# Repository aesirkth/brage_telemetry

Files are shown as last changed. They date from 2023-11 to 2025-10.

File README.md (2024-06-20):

## Brage Telemetry modem
Brage is a 1W 2.4GHz Telemetry modem that can listen and transmit from a CAN-bus. The name comes from the norse god of poetry, Brage, who will tell the tales of the rocket.

| front | back |
|---|---|
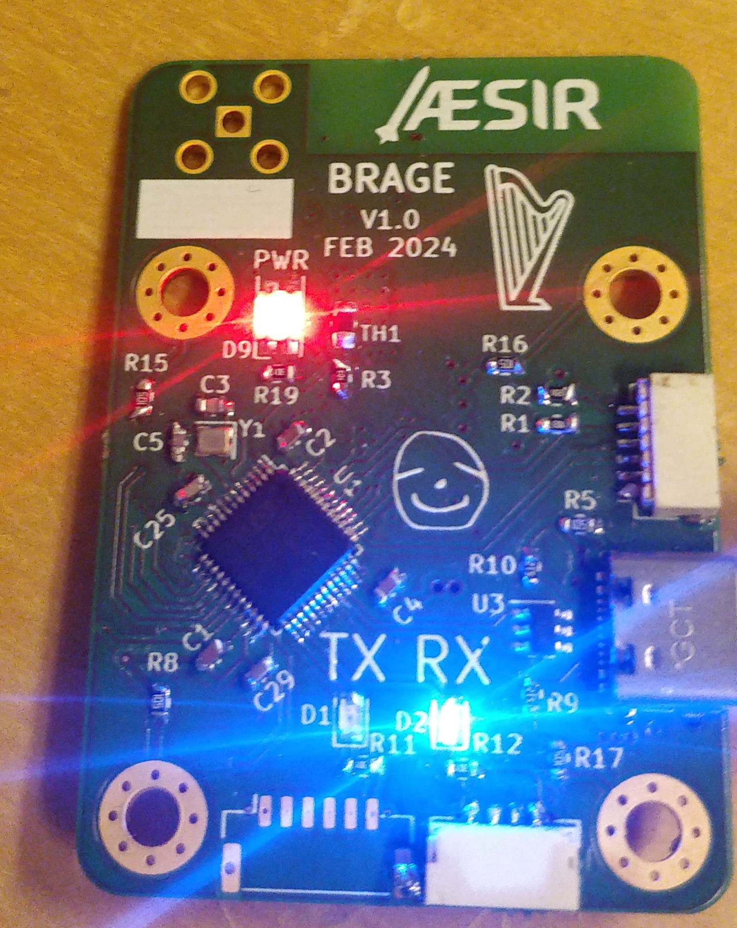
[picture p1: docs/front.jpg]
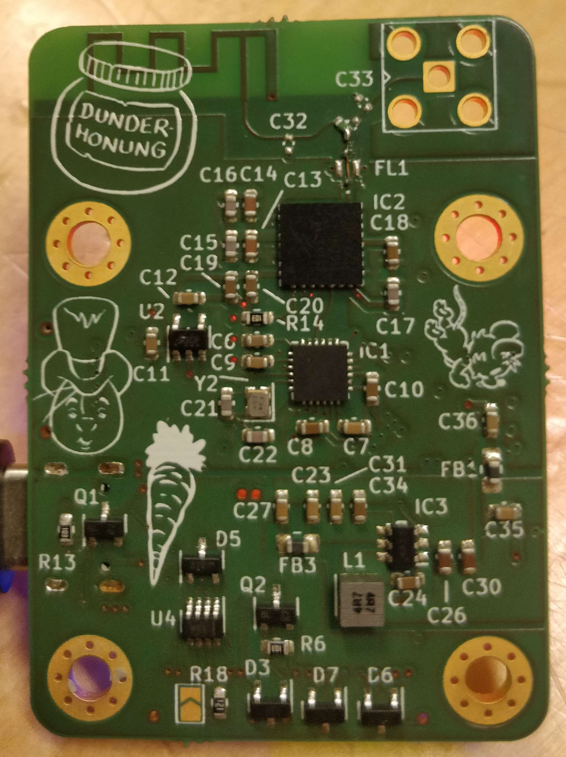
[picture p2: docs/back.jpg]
| | |

### Features
* 2Mbit/s
* Time of Flight ranging
* CAN FD with SIC
* UART
* USB
* PCB antenna

### Hardware
The modem is based on an STM32U575CG and an SX1280 transceiver. The radio signal is put through a frontend, filtering and amplifying it to 30dBm. The UART and CAN connectors follow the PixHawk standard while the debugging port is custom.

### Firmware
The firmware is being developed using Rust with Embassy.
See the firmware [README](firmware/README.md)

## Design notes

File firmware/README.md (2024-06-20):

## Brage firmware
### Building
Brage is built using Rust and the Embassy framework. `cargo build --release`. I don't have a proper build guide yet but cargo should point out the missing dependencies (I think). Cargo should fetch most of the dependencies itself. You might need to install at least rustup and Probe-rs yourself.

To flash the board, just run `cargo run --release`

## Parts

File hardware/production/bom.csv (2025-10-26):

Designator | Footprint | Quantity | Value | LCSC Part #
AE1 | Texas_SWRA117D_2.4GHz_Left | 1 | inverted F
C1, C13, C14, C2, C4 | 0603 | 5 | 4u7
C10, C18, C19, C20, C24, C25, C29, C34, C8 | 0603 | 9 | 100n
C11, C12, C23, C27, C31, C35, C36, C7 | 0603 | 8 | 1u
C15, C16, C17, C21, C22, C3, C5 | 0603 | 7 | 18p
C26, C30 | 0603 | 2 | 10u
C32, C33 | 0402 | 2 | TBD
C6, C9 | 0603 | 2 | 10n
D1 | 0805 | 1 | tx
D2 | 0805 | 1 | rx
D3, D5, D6, D7 | SOT-23 | 4 | SZNUP2105L
D9 | LED_RGB_1210 | 1 | IN-S128TATRGB
FB1, FB3 | 0805 | 2 | BLM18KG102SN1D
FL1 | DEA202450BT1261A2 | 1 | DEA202450BT-1213C1
H1, H2, H3, H4 | MountingHole_3.2mm_M3_Pad_Via | 4 | MountingHole_Pad
IC1 | QFN50P400X400X100-25N-D | 1 | SX1281IMLTRT
IC2 | SKY6538311 | 1 | SKY65383-11
IC3 | SOT95P280X145-6N | 1 | LMR50410Y3
J1 | JST_SH_SM06B-SRSS-TB_1x06-1MP_P1.00mm_Horizontal | 1 | jst_sh 6
J2 | SMA_Amphenol_901-143_Horizontal | 1 | Conn_Coaxial
J3 | USB_C_Receptacle_Palconn_UTC16-G | 1 | USB_C_Receptacle_USB2.0
J4 | JST_GH_SM04B-GHS-TB_1x04-1MP_P1.25mm_Horizontal | 1 | jst gh 4
J5 | JST_GH_SM06B-GHS-TB_1x06-1MP_P1.25mm_Horizontal | 1 | jst gh 6
JP1 | SolderJumper-2_P1.3mm_Open_TrianglePad1.0x1.5mm | 1 | SolderJumper_2_Open
L1 | L_Wurth_WE-LQSH-3012 | 1 | 4.7u
Q1, Q2 | SOT-23 | 2 | DMP3056L-7
R1, R13, R14, R2, R3, R6 | 0603 | 6 | 10k
R10, R9 | 0603 | 2 | 5k1
R11, R12, R19, R20, R21 | 0603 | 5 | 330
R15, R16, R17, R5, R8 | 0603 | 5 | 1M
R18 | 0603 | 1 | 120
R4, R7 | 0402 | 2 | 0
TH1 | 0805 | 1 | NTCG203NH103JT1
U1 | LQFP-48_7x7mm_P0.5mm | 1 | STM32U575CGTx
U2 | SOT-23-5 | 1 | TPS7A20285PDBVR
U3 | SOT-23-6 | 1 | USBLC6-2SC6
U4 | TSOT-23-8 | 1 | TCAN334GDCN
Y1 | Crystal_SMD_2016-4Pin_2.0x1.6mm | 1 | 48MHz
Y2 | Crystal_SMD_2016-4Pin_2.0x1.6mm | 1 | 52MHz

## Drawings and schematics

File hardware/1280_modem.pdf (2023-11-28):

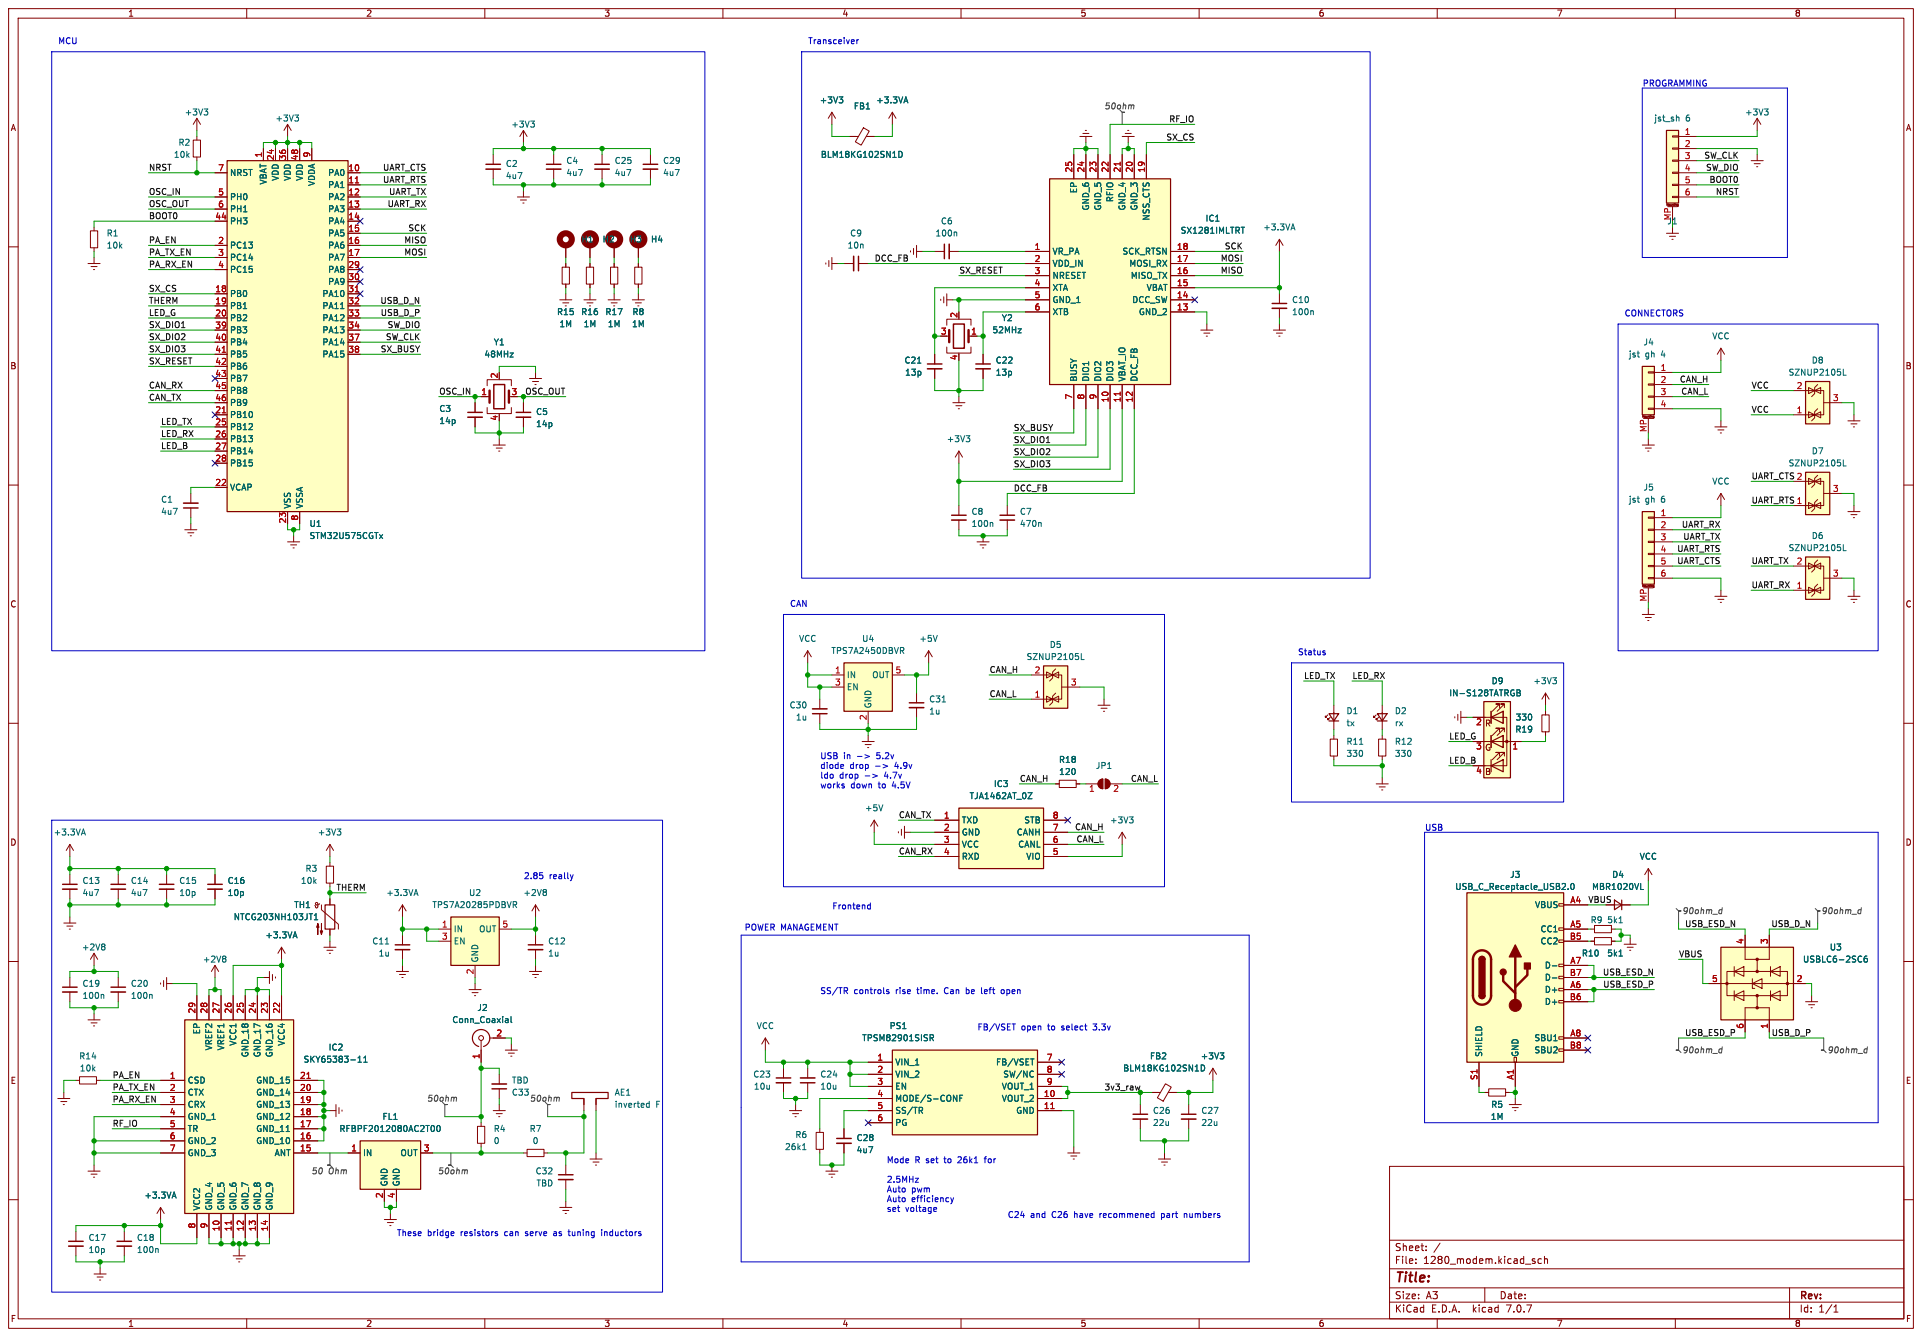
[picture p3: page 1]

1 PA0 10 PA1 11 PA2 12 PA3 13 PA4 14 PA5 15 PA6 16 PA7 17 PB0 18 PB1 19 PC13 2 PB2 20 PB10 21 VCAP 22 VSS 23 VDD 24 PB12 25 PB13 26 PB14 27 PB15 28 PA8 29 PC14 3 PA9 30 PA10 31 PA11 32 PA12 33 PA13 34 VDD 36 PA14 37 PA15 38 PB3 39 PC15 4 PB4 40 PB5 41 PB6 42 PB7 43 PH3 44 PB8 45 PB9 46 VDD 48 PH0 5 PH1 6 NRST 7 VSSA

Id: 1/1 Title: File: 1280_modem.kicad_sch Sheet: /

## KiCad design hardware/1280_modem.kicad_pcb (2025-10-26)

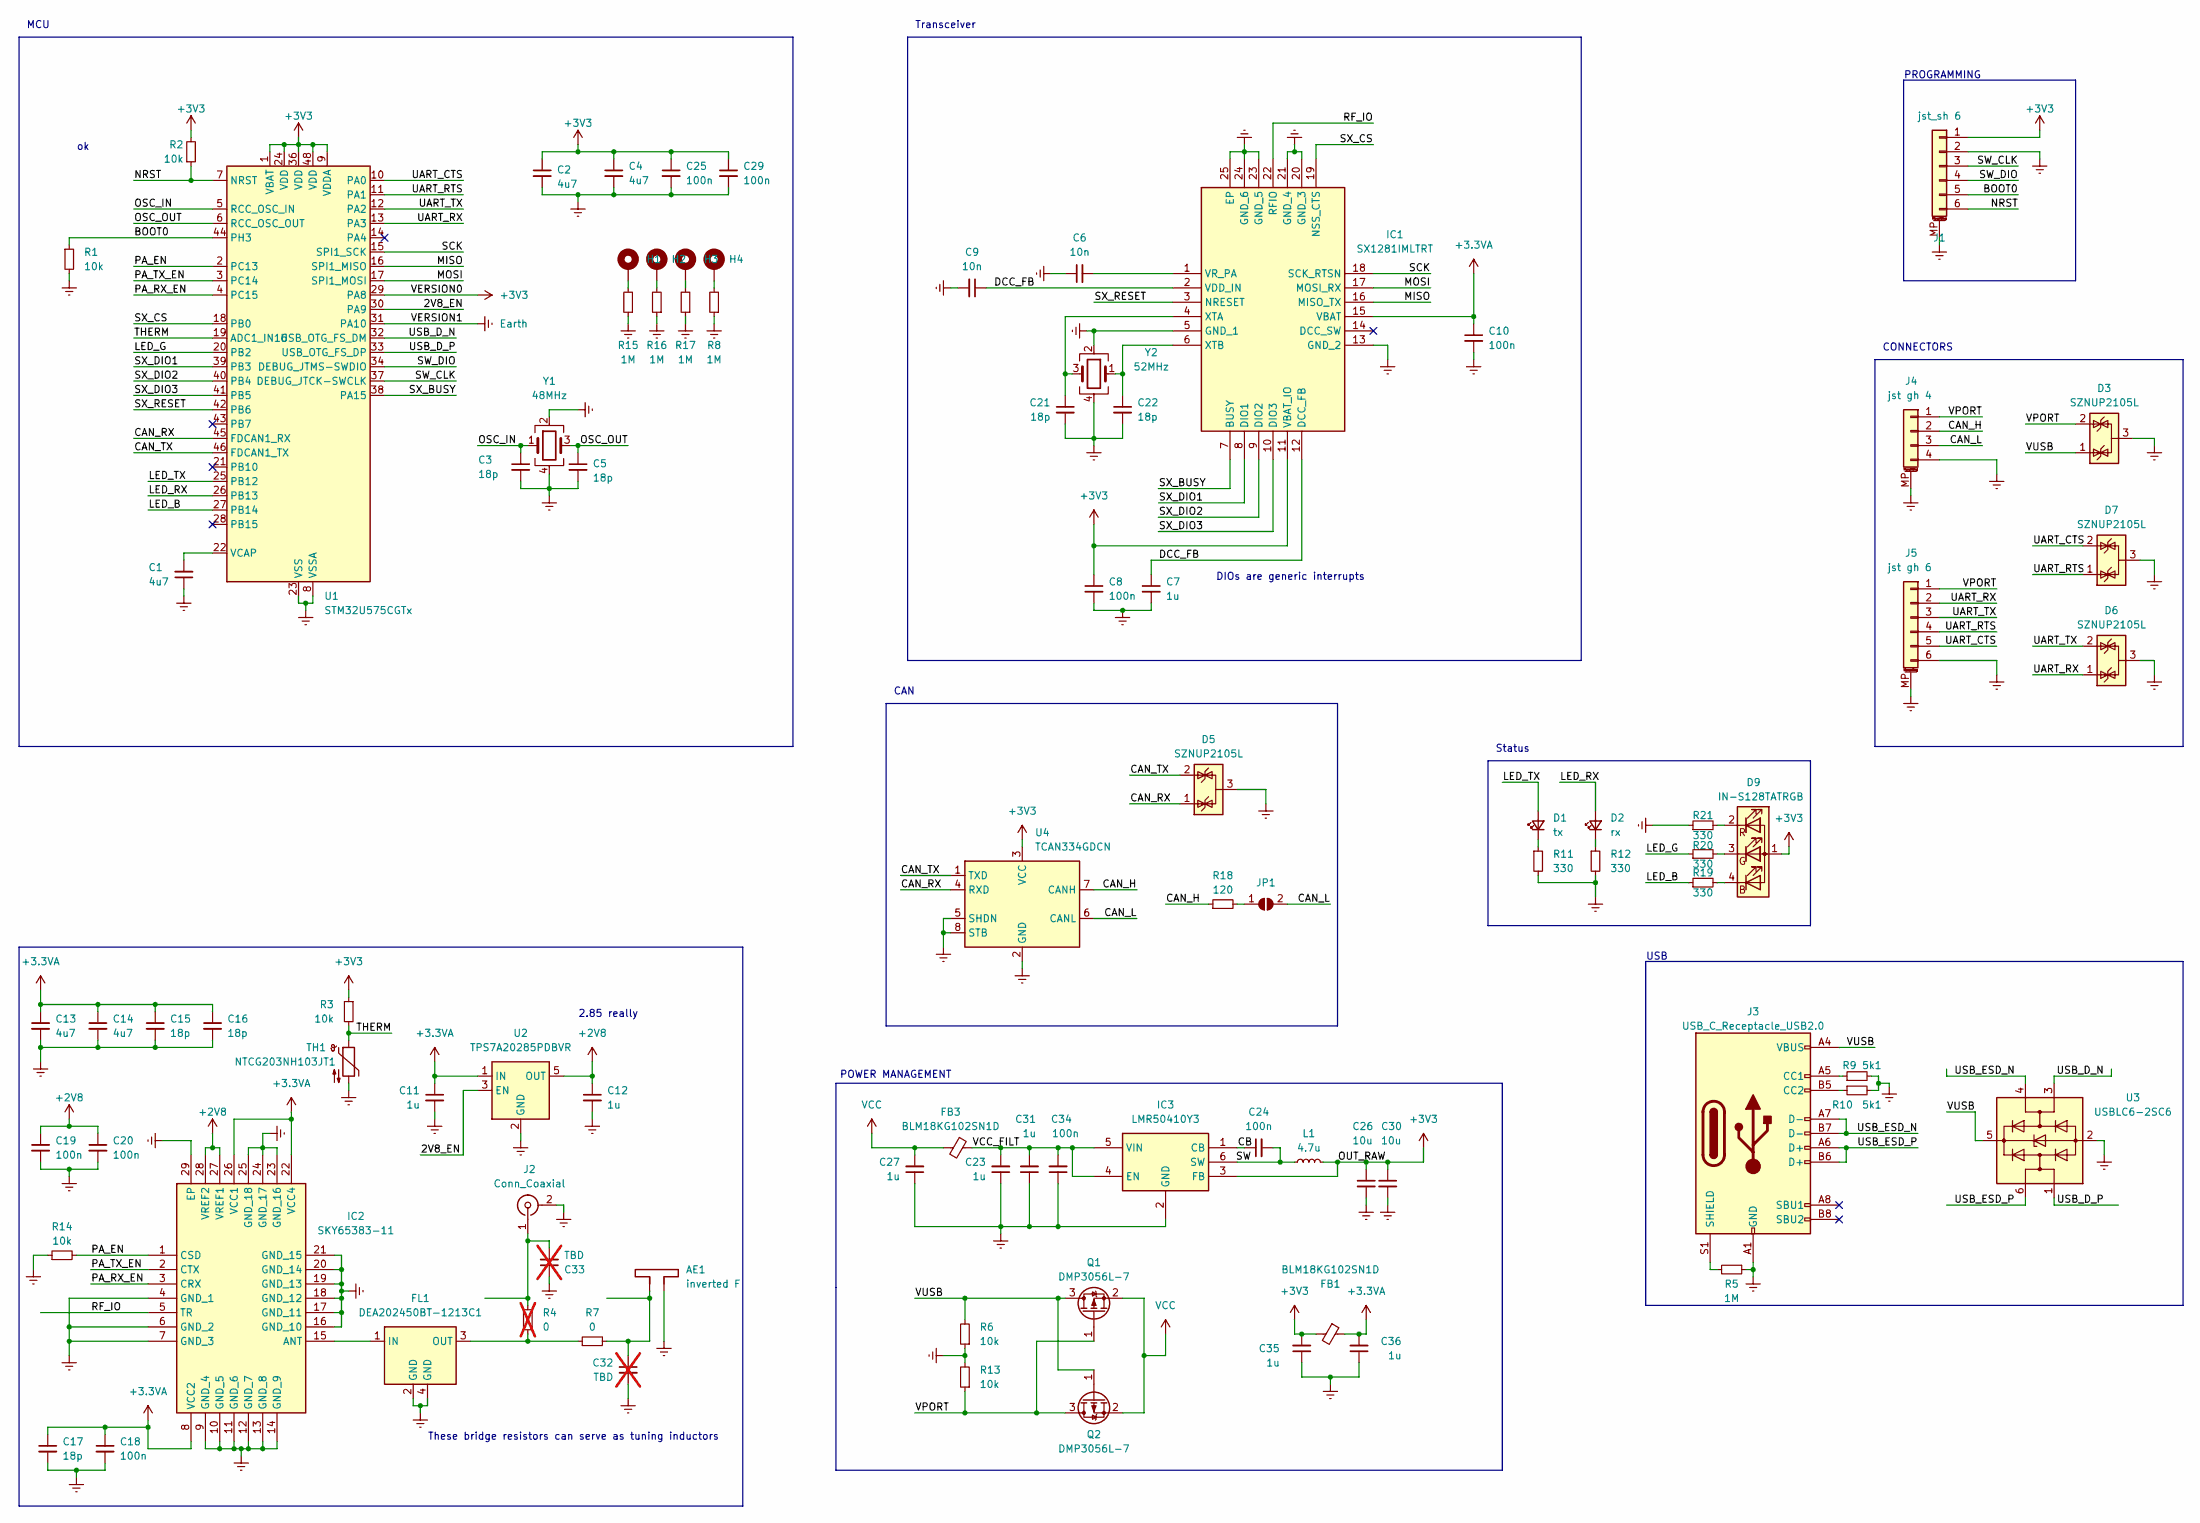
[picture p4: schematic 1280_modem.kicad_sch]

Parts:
AE1: inverted F; Texas_SWRA117D_2.4GHz_Left
C1, C2, C4, C13, C14: 4u7; C_0603_1608Metric
C3, C5, C15, C16, C17, C21, C22: 18p; C_0603_1608Metric
C6, C9: 10n; C_0603_1608Metric
C7, C11, C12, C23, C27, C31, C35, C36: 1u; C_0603_1608Metric
C8, C10, C18, C19, C20, C24, C25, C29, C34: 100n; C_0603_1608Metric
C26, C30: 10u; C_0603_1608Metric
C32, C33: TBD; C_0402_1005Metric; not fitted
D1: tx; LED_0805_2012Metric
D2: rx; LED_0805_2012Metric
D3, D5, D6, D7: SZNUP2105L; SOT-23
D9: IN-S128TATRGB; LED_RGB_1210
FB1, FB3: BLM18KG102SN1D; L_0805_2012Metric_Pad1.15x1.40mm_HandSolder
FL1: DEA202450BT-1213C1; DEA202450BT1261A2; Mouser Part Number 810-DEA2024BT1261A2
H1, H2, H3, H4: MountingHole_Pad; MountingHole_3.2mm_M3_Pad_Via
IC1: SX1281IMLTRT; QFN50P400X400X100-25N-D; Mouser Part Number 947-SX1281IMLTRT
IC2: SKY65383-11; SKY6538311; Mouser Part Number 873-SKY65383-11
IC3: LMR50410Y3; SOT95P280X145-6N; Mouser Part Number 595-LMR50410YQDBVRQ1
J1: jst_sh 6; JST_SH_SM06B-SRSS-TB_1x06-1MP_P1.00mm_Horizontal
J2: Conn_Coaxial; SMA_Amphenol_901-143_Horizontal
J3: USB_C_Receptacle_USB2.0; USB_C_Receptacle_Palconn_UTC16-G
J4: jst gh 4; JST_GH_SM04B-GHS-TB_1x04-1MP_P1.25mm_Horizontal
J5: jst gh 6; JST_GH_SM06B-GHS-TB_1x06-1MP_P1.25mm_Horizontal
JP1: SolderJumper_2_Open; SolderJumper-2_P1.3mm_Open_TrianglePad1.0x1.5mm
L1: 4.7u; L_Wurth_WE-LQSH-3012
Q1, Q2: DMP3056L-7; SOT-23
R1, R2, R3, R6, R13, R14: 10k; R_0603_1608Metric
R4: 0; R_0402_1005Metric; not fitted
R5, R8, R15, R16, R17: 1M; R_0603_1608Metric
R7: 0; R_0402_1005Metric
R9, R10: 5k1; R_0603_1608Metric
R11, R12, R19, R20, R21: 330; R_0603_1608Metric
R18: 120; R_0603_1608Metric
TH1: NTCG203NH103JT1; R_0805_2012Metric_Pad1.20x1.40mm_HandSolder
U1: STM32U575CGTx; LQFP-48_7x7mm_P0.5mm
U2: TPS7A20285PDBVR; SOT-23-5
U3: USBLC6-2SC6; SOT-23-6
U4: TCAN334GDCN; TSOT-23-8
Y1: 48MHz; Crystal_SMD_2016-4Pin_2.0x1.6mm
Y2: 52MHz; Crystal_SMD_2016-4Pin_2.0x1.6mm

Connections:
+2V8: C12.1, C19.1, C20.1, IC2.27 (VREF1), IC2.28 (VREF2), U2.5 (OUT)
+3.3VA: C10.1, C11.1, C13.1, C14.1, C15.1, C16.1, C17.1, C18.1, C36.2, FB1.1, IC1.15 (VBAT), IC2.8 (VCC2), IC2.22 (VCC4), IC2.26 (VCC1), U2.1 (IN)
+3V3: C2.1, C4.1, C8.1, C25.1, C26.1, C29.1, C30.1, C35.2, D9.1 (A), FB1.2, IC1.11 (VBAT_IO), IC3.3 (FB), J1.1, L1.2, R2.2, R3.1, U1.1 (VBAT), U1.9 (VDDA), U1.24 (VDD), U1.29 (PA8), U1.36 (VDD), U1.48 (VDD), U4.3 (VCC)
/2V8_EN: U1.30 (PA9), U2.3 (EN)
/BOOT0: J1.5, R1.1, U1.44 (PH3)
/CAN_H: J4.2, R18.1, U4.7 (CANH)
/CAN_L: J4.3, JP1.2 (B), U4.6 (CANL)
/CAN_RX: D5.1 (K), U1.45 (FDCAN1_RX), U4.4 (RXD)
/CAN_TX: D5.2 (K), U1.46 (FDCAN1_TX), U4.1 (TXD)
/CB: C24.1, IC3.1 (CB)
/DCC_FB: C7.1, C9.1, IC1.2 (VDD_IN), IC1.12 (DCC_FB)
/LED_B: R19.1, U1.27 (PB14)
/LED_G: R20.1, U1.20 (PB2)
/LED_RX: D2.2 (A), U1.26 (PB13)
/LED_TX: D1.2 (A), U1.25 (PB12)
/MISO: IC1.16 (MISO_TX), U1.16 (SPI1_MISO)
/MOSI: IC1.17 (MOSI_RX), U1.17 (SPI1_MOSI)
/NRST: J1.6, R2.1, U1.7 (NRST)
/OSC_IN: C3.1, U1.5 (RCC_OSC_IN), Y1.1
/OSC_OUT: C5.1, U1.6 (RCC_OSC_OUT), Y1.3
/PA_EN: IC2.1 (CSD), R14.2, U1.2 (PC13)
/PA_RX_EN: IC2.3 (CRX), U1.4 (PC15)
/PA_TX_EN: IC2.2 (CTX), U1.3 (PC14)
/RF_IO: IC1.22 (RFIO), IC2.5 (TR)
/SCK: IC1.18 (SCK_RTSN), U1.15 (SPI1_SCK)
/SW: C24.2, IC3.6 (SW), L1.1
/SW_CLK: J1.3, U1.37 (DEBUG_JTCK-SWCLK)
/SW_DIO: J1.4, U1.34 (DEBUG_JTMS-SWDIO)
/SX_BUSY: IC1.7 (BUSY), U1.38 (PA15)
/SX_CS: IC1.19 (NSS_CTS), U1.18 (PB0)
/SX_DIO1: IC1.8 (DIO1), U1.39 (PB3)
/SX_DIO2: IC1.9 (DIO2), U1.40 (PB4)
/SX_DIO3: IC1.10 (DIO3), U1.41 (PB5)
/SX_RESET: IC1.3 (NRESET), U1.42 (PB6)
/THERM: R3.2, TH1.1, U1.19 (ADC1_IN16)
/UART_CTS: D7.2 (K), J5.5, U1.10 (PA0)
/UART_RTS: D7.1 (K), J5.4, U1.11 (PA1)
/UART_RX: D6.1 (K), J5.2, U1.13 (PA3)
/UART_TX: D6.2 (K), J5.3, U1.12 (PA2)
/USB_D_N: U1.32 (USB_OTG_FS_DM), U3.3 (I/O2)
/USB_D_P: U1.33 (USB_OTG_FS_DP), U3.1 (I/O1)
/USB_ESD_N: J3.A7 (D-), J3.B7 (D-), U3.4 (I/O2)
/USB_ESD_P: J3.A6 (D+), J3.B6 (D+), U3.6 (I/O1)
/VCC_FILT: C23.2, C31.2, C34.2, FB3.1, IC3.4 (EN), IC3.5 (VIN)
/VPORT: D3.2 (K), J4.1, J5.1, Q1.1 (G), Q2.3 (D), R13.1
/VUSB: D3.1 (K), J3.A4 (VBUS), J3.A9 (VBUS), J3.B4 (VBUS), J3.B9 (VBUS), Q1.3 (D), Q2.1 (G), R6.2, U3.5 (VBUS)
Earth: AE1.2, C1.1, C2.2, C3.2, C4.2, C5.2, C6.1, C7.2, C8.2, C9.2, C10.2, C11.2, C12.2, C13.2, C14.2, C15.2, C16.2, C17.2, C18.2, C19.2, C20.2, C21.2, C22.2, C23.1, C25.2, C26.2, C27.1, C29.2, C30.2, C31.1, C32.2, C33.1, C34.1, C35.1, C36.1, D3.3 (A), D5.3 (A), D6.3 (A), D7.3 (A), FL1.2 (GND), FL1.4 (GND), IC1.5 (GND_1), IC1.13 (GND_2), IC1.20 (GND_3), IC1.21 (GND_4), IC1.23 (GND_5), IC1.24 (GND_6), IC1.25 (EP), IC2.4 (GND_1), IC2.6 (GND_2), IC2.7 (GND_3), IC2.9 (GND_4), IC2.10 (GND_5), IC2.11 (GND_6), IC2.12 (GND_7), IC2.13 (GND_8), IC2.14 (GND_9), IC2.16 (GND_10), IC2.17 (GND_11), IC2.18 (GND_12), IC2.19 (GND_13), IC2.20 (GND_14), IC2.21 (GND_15), IC2.23 (GND_16), IC2.24 (GND_17), IC2.25 (GND_18), IC2.29 (EP), IC3.2 (GND), J1.2, J1.MP (MountPin), J2.2 (Ext), J3.A1 (GND), J3.A12 (GND), J3.B1 (GND), J3.B12 (GND), J4.4, J4.MP (MountPin), J5.6, J5.MP (MountPin), R1.2, R5.1, R6.1, R8.1, R9.2, R10.2, R11.2, R12.2, R13.2, R14.1, R15.1, R16.1, R17.1, R21.1, TH1.2, U1.8 (VSSA), U1.23 (VSS), U1.31 (PA10), U1.35 (VSS), U1.47 (VSS), U2.2 (GND), U3.2 (GND), U4.2 (GND), U4.5 (SHDN), U4.8 (STB), Y1.2, Y1.4, Y2.2, Y2.4
unnamed: AE1.1, C32.1, R7.2
unnamed: D1.1 (K), R11.1
unnamed: D2.1 (K), R12.1
unnamed: D9.4 (BK), R19.2
unnamed: D9.3 (GK), R20.2
unnamed: D9.2 (RK), R21.2
unnamed: FL1.1 (IN), IC2.15 (ANT)
unnamed: FL1.3 (OUT), R4.1, R7.1
unnamed: H1.1, R15.2
unnamed: H2.1, R16.2
unnamed: H3.1, R17.2
unnamed: H4.1, R8.2
unnamed: C6.2, IC1.1 (VR_PA)
unnamed: C21.1, IC1.4 (XTA), Y2.3
unnamed: C22.1, IC1.6 (XTB), Y2.1
unnamed: C33.2, J2.1 (In), R4.2
unnamed: J3.A5 (CC1), R9.1
unnamed: J3.B5 (CC2), R10.1
unnamed: J3.S1 (SHIELD), R5.2
unnamed: JP1.1 (A), R18.2
unnamed: C1.2, U1.22 (VCAP)
VCC: C27.2, FB3.2, Q1.2 (S), Q2.2 (S)

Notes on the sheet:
CAN
2.85 really
PROGRAMMING
Status
POWER MANAGEMENT
MCU
DIOs are generic interrupts
CONNECTORS
USB
These bridge resistors can serve as tuning inductors
Transceiver

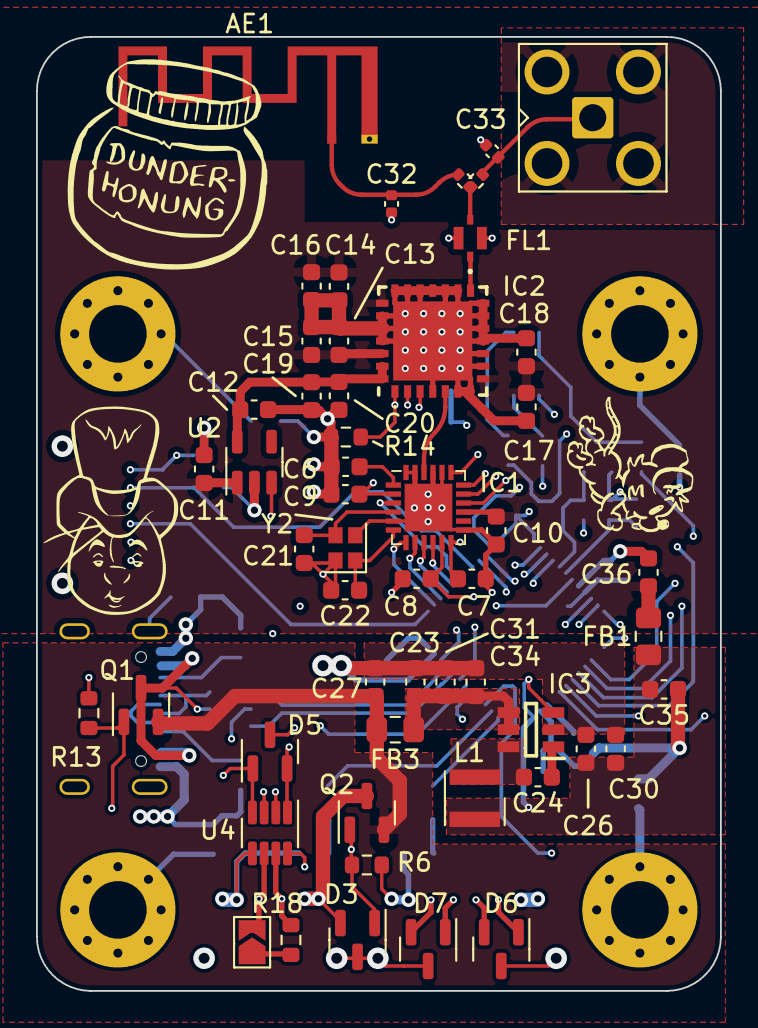
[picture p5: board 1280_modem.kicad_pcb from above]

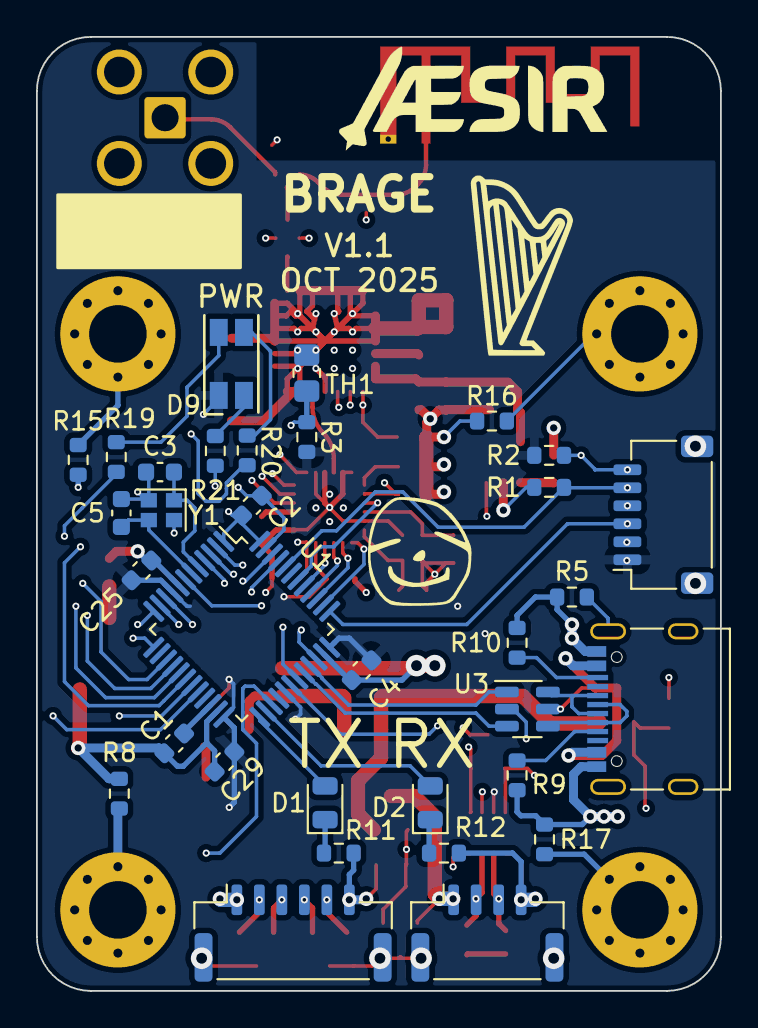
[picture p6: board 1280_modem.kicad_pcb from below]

Board: 4 copper layers, 38.0 x 53.0 mm, 90 parts (35 on the bottom side), 69 nets.

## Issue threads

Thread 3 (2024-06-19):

Fix radio

klownfish, 2024-06-19:
The radio transceiver doesn't work, most likely a driver issue

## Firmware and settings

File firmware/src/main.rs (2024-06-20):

#![no_std]
#![no_main]


use defmt::{*};
use defmt_rtt as _;


use embassy_stm32::peripherals::{FDCAN1, USB_OTG_FS, USART2};
use embassy_stm32::time::Hertz;
use embassy_stm32::gpio::{Level, Output, Pull, Speed};
use embassy_stm32::exti::ExtiInput;
use embassy_sync::blocking_mutex::raw::ThreadModeRawMutex;
use embassy_sync::channel::Channel;


use panic_probe as _;

pub mod sx_hal;
pub mod protocol;

pub static UART_IN: Channel<ThreadModeRawMutex, protocol::UartMsg, 32> = Channel::new();
pub static UART_OUT: Channel<ThreadModeRawMutex, protocol::UartMsg, 32> = Channel::new();

pub static CAN_OUT: Channel<ThreadModeRawMutex, protocol::CanMsg, 32> = Channel::new();
pub static CAN_IN: Channel<ThreadModeRawMutex, protocol::CanMsg, 32> = Channel::new();

mod radio;
mod can;
mod uart;

embassy_stm32::bind_interrupts!(struct Irqs {
    OTG_FS => embassy_stm32::usb::InterruptHandler<USB_OTG_FS>;
    FDCAN1_IT0 => embassy_stm32::can::IT0InterruptHandler<FDCAN1>;
    FDCAN1_IT1 => embassy_stm32::can::IT1InterruptHandler<FDCAN1>;
    USART2 => embassy_stm32::usart::BufferedInterruptHandler<USART2>;
});


#[embassy_executor::task]
async fn logger_task(driver: embassy_stm32::usb::Driver<'static, USB_OTG_FS>) -> ! {
    embassy_usb_logger::run!(1024, log::LevelFilter::Trace, driver);
    loop {
        core::panic!("unreachable");
    }
}

#[embassy_executor::main]
async fn main(spawner: embassy_executor::Spawner) {
    let mut config = embassy_stm32::Config::default();
    {
        use embassy_stm32::rcc::*;
        config.rcc.hsi = true;
        config.rcc.hse = Some(Hse {
            freq: Hertz(48_000_000),
            mode: HseMode::Oscillator
        });
        config.rcc.pll1 = Some(Pll {
            source: PllSource::HSE, // 48 MHz
            prediv: PllPreDiv::DIV3, // 16 MHz
            mul: PllMul::MUL10, // 160 MHz
            divp: Some(PllDiv::DIV2),
            divq: Some(PllDiv::DIV2),
            divr: Some(PllDiv::DIV1), // 160 MHz
        });
        config.rcc.sys = Sysclk::PLL1_R;
        config.rcc.voltage_range = VoltageScale::RANGE1;
        config.rcc.hsi48 = Some(Hsi48Config { sync_from_usb: true }); // needed for USB
        config.rcc.mux.iclksel = mux::Iclksel::HSI48; // USB uses ICLK
    }

    let p = embassy_stm32::init(config);

    // Create the driver, from the HAL.
    static mut USB_BUF: core::cell::UnsafeCell<[u8; 1024]> = core::cell::UnsafeCell::new([0; 1024]);
    let mut config = embassy_stm32::usb::Config::default();
    config.vbus_detection = false;
    let usb_driver = embassy_stm32::usb::Driver::new_fs(p.USB_OTG_FS, Irqs, p.PA12, p.PA11, unsafe {USB_BUF.get_mut()}, config);
    // spawner.spawn(logger_task(usb_driver)).unwrap();

    info!("Hello World!");

    let sx_cs = Output::new(p.PB0, Level::High, Speed::VeryHigh);
    let sx_reset = Output::new(p.PB6, Level::High, Speed::VeryHigh);
    let sx_dio1 = ExtiInput::new(p.PB3, p.EXTI3, Pull::Down);
    let sx_dio2 = ExtiInput::new(p.PB4, p.EXTI4, Pull::Down);
    let sx_dio3 = ExtiInput::new(p.PB5, p.EXTI5, Pull::Down);
    let sx_busy = ExtiInput::new(p.PA15, p.EXTI15, Pull::Down);

    let led_tx = Output::new(p.PB12, Level::Low, Speed::VeryHigh);
    let led_rx = Output::new(p.PB13, Level::Low, Speed::VeryHigh);

    let pa_en = Output::new(p.PC13, Level::Low, Speed::VeryHigh);
    let pa_tx_en = Output::new(p.PC14, Level::Low, Speed::VeryHigh);
    let pa_rx_en = Output::new(p.PC15, Level::Low, Speed::VeryHigh);
    let vref_en = Output::new(p.PB2, Level::Low, Speed::VeryHigh); // soldered to LED G with a jumper

    let mut can_configurator = embassy_stm32::can::CanConfigurator::new(p.FDCAN1, p.PB8, p.PB9, Irqs);

    can_configurator.set_bitrate(500_000);

    can_configurator.set_fd_data_bitrate(1_000_000, true);

    let can = can_configurator.start(embassy_stm32::can::OperatingMode::NormalOperationMode);

    static mut CAN_TX_BUF: core::cell::UnsafeCell<embassy_stm32::can::TxFdBuf<1024>> = core::cell::UnsafeCell::new(embassy_stm32::can::TxFdBuf::new());
    static mut CAN_RX_BUF: core::cell::UnsafeCell<embassy_stm32::can::RxFdBuf<1024>> = core::cell::UnsafeCell::new(embassy_stm32::can::RxFdBuf::new());

    let can = can.buffered_fd(unsafe{CAN_TX_BUF.get_mut()}, unsafe {CAN_RX_BUF.get_mut()});

    let can_rx = can.reader();
    let can_tx = can.writer();

    let mut spi_config = embassy_stm32::spi::Config::default();
    spi_config.frequency = Hertz(10_000_000);

    let spi = embassy_stm32::spi::Spi::new(p.SPI1, p.PA5, p.PA7, p.PA6, p.GPDMA1_CH0, p.GPDMA1_CH1, spi_config);

    static mut UART_TX_BUF: core::cell::UnsafeCell<[u8; 512]> = core::cell::UnsafeCell::new([0; 512]);
    static mut UART_RX_BUF: core::cell::UnsafeCell<[u8; 512]> = core::cell::UnsafeCell::new([0; 512]);
    let config = embassy_stm32::usart::Config::default();
    let uart = embassy_stm32::usart::BufferedUart::new_with_rtscts(p.USART2, Irqs, p.PA3, p.PA2, p.PA1, p.PA0, unsafe {UART_TX_BUF.get_mut()}, unsafe {UART_RX_BUF.get_mut()}, config).unwrap();

    let (uart_tx, uart_rx) = uart.split();
    spawner.spawn(radio::radio_task(spi, sx_cs, sx_busy, sx_reset, sx_dio1, sx_dio2, sx_dio3, led_tx, led_rx, pa_en, pa_tx_en, pa_rx_en, vref_en)).unwrap();
    spawner.spawn(can::can_reader_task(can_rx)).unwrap();
    spawner.spawn(can::can_writer_task(can_tx)).unwrap();
    spawner.spawn(uart::uart_writer_task(uart_tx)).unwrap();
    spawner.spawn(uart::uart_reader_task(uart_rx)).unwrap();
}

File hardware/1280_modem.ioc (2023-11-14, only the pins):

Mcu.UserName=STM32U575CGTx
PA0.Signal=USART2_CTS
PA1.Signal=USART2_RTS
PA10.Signal=USART1_RX
PA11.Signal=USB_OTG_FS_DM
PA12.Signal=USB_OTG_FS_DP
PA2.Signal=USART2_TX
PA3.Signal=USART2_RX
PA5.Signal=SPI1_SCK
PA6.Signal=SPI1_MISO
PA7.Signal=SPI1_MOSI
PA9.Signal=USART1_TX
PB0.Signal=SPI1_NSS

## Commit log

2023-11-14 add pdf schematic
2023-11-14 fix drc
    [1280_modem.kicad_pcb]
2023-11-14 prettier thermal vias
    [1280_modem.kicad_pcb]
2023-11-19 prettier schematic
    [1280_modem.kicad_sch]
2023-11-27 micro strip and antenna tuning
    [1280_modem.kicad_pcb, 1280_modem.kicad_sch]
2023-11-28 add pdf
    [1280_modem.kicad_sch]
2024-02-05 better power electronics
    [1280_modem.kicad_pcb, 1280_modem.kicad_sch]
2024-02-27 second pass
    [1280_modem.kicad_pcb, 1280_modem.kicad_sch]
2024-03-11 final 4 layer version
    [1280_modem.kicad_pcb]
2024-03-12 ordered version
    [1280_modem.kicad_pcb]
2024-03-28 fix bom
    [1280_modem.kicad_sch]
2024-03-29 final (?) bom
    [1280_modem.kicad_pcb, 1280_modem.kicad_sch]
